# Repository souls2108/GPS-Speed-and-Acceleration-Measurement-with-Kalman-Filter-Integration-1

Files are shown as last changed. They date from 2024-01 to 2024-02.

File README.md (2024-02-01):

# GPS-Speed-and-Acceleration-Measurement-with-Kalman-Filter-Integration
 GPS-based system for accurately measuring speed and acceleration, applying Kalman filtering techniques for enhanced precision. The system further includes a user-friendly OLED display for real-time speed visualization.

### Description:

GPS Speedometer project repository: This open-source project aims to provide a comprehensive GPS-based system for accurately measuring speed and acceleration, applying Kalman filtering techniques for enhanced precision. The system further includes a 1.5 inch OLED display for real-time speed visualization and a web interface for remote monitoring.<b>This project was implemented to measure vehicle telemetry for Team Firebolt Racing in mBAJA 2024 (SAEINDIA).</b>

### Hardware used:
<ol>
 <li>ublox NEO-6M</li>
 <li><a href="https://robu.in/product/gps-glonass-gnss-antenna-for-raspberry-pi-hat-and-arduino-shield-with-3-meter-cable/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">GPS antenna (for better performance)</a></li>
 <li>BNO085 9DoF (accelerometer, gyroscope, magnetometer)</li>
 <li>NodeMCU v1.0</li>
 <li>1.5 inch OLED display by Waveshare [SSD1327]</li>
</ol>

## Features:
## 1. GPS-Based Speed and Acceleration Measurement
Utilizing GPS data, the system accurately calculates and measures real-time speed and acceleration. The integration of GPS technology ensures reliable and precise location-based speed readings.

## 2. Kalman Filter Implementation
To enhance the accuracy of speed and acceleration measurements, a Kalman filter is applied. The Kalman filter optimally combines GPS data with accelerometer readings, resulting in more reliable and smoother speed values, particularly in scenarios with signal noise or intermittent GPS connectivity.

## 3. OLED Display
The project includes an OLED display to provide a convenient and intuitive interface for users to monitor their speed in real time. The display showcases clear and easily readable speed information, making it suitable for various applications, such as automotive or fitness devices.

## 4. Webpage Display
For remote monitoring and data visualization, the system features a web interface. Users can access a webpage that displays real-time speed information, allowing for convenient monitoring without the need for physical interaction with the OLED display. The web interface supports multiple devices, providing a flexible and accessible solution.

## Getting Started:
1. Clone the repository to your local machine.
2. Install the required dependencies mentioned in the documentation.
3. Make the required changes in configuration to GPS module using U - Center software.
4. Connect the GPS module, BNO085 and OLED display to NodeMCU to set-up. 
5. Upload the provided code to your microcontroller.
6. Access the web interface to monitor real-time speed remotely.

### Port Map
<ul>
  <li>OLED SCREEN</li>
   <ol>
    <li>VCC -> 3V</li>
    <li>GND -> GND</li>
    <li>DIN -> D7</li>
    <li>CLK -> D5</li>
    <li>CS -> D8</li>
    <li>DC -> D0</li>
    <li>RST -> D3</li>
   </ol>

  <li>BNO085</li>
   <ol>
    <li>VIN -> 3V</li>
    <li>GND -> GND</li>
    <li>SCL -> D1</li>
    <li>SDA -> D2</li>
    <li>P0 -> GND</li>
    <li>P1 -> GND</li>
   </ol>

   <li>GPS</li>
   <ol>
    <li>VCC -> 3V</li>
    <li>GND -> GND</li>
    <li>RX -> D4</li>
    <li>TX -> D6</li>
   </ol>
</ul>

## Contribution Guidelines:
Welcome for contributions to enhance and expand the capabilities of this GPS speedometer system. Feel free to submit bug reports, feature requests, or pull requests to help improve the project.

Thank you for choosing our GPS Speedometer project. We hope it proves to be a valuable tool for your speed measurement and monitoring needs!

## References
<ul>
 <li>
  <a href = "https://youtu.be/TwhCX0c8Xe0?si=p0fIQ2RGdnS_CM2-">GPS Configuration Reference</a>
 </li>
 <li>
  <a href="https://github.com/olikraus/u8g2.git">Library for OLED display</a>
 </li>
 <li>
  <a href = "https://github.com/adafruit/Adafruit_BNO08x.git">Library for BNO085</a>
 </li>
 <li>
  <a href="https://youtu.be/6M6wSLD-8M8?si=LIJLbGDBOQZDQuQw">Kalman Filter Basics</a>
 </li>
 <li>
  <a href="https://github.com/morrissinger/ESP8266-Websocket.git">ESP8266 Web Sockets</a>
 </li>
</ul>

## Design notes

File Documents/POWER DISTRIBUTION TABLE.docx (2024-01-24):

# POWER DISTRIBUTION TABLE

UNIT NAME | SAMPLE RATE (Hz) | POWER (mW)
IMU – BNO085 | 400 | 45.45
GPS module – Ublox Neo 6M | 5 | 165
Oled display – SSD1327 | - | 13.2 - 198
Node MCU | | 231 - 495
| | 454.65 - 903.45

Typical hours of operation – 20 Hr

Operating Voltage – 3.3 V

Energy consumption – {454.65 - 903.45} x 20 = {9093 – 18069} mWh

= {9093 – 18069} ÷ 3.3 = {2755.45 – 5475.45} mAh

Operating power of Brake light = 1 W

Typical hours of operation = 10 Hr

Typical operating voltage = 7 V

Energy consumption = 1 x 10 = 10 Wh

= (10×1000)/7= 1428.57 mAh

NET ENERGY CONSUMPTION = {4184.02 – 6904.02} mAh

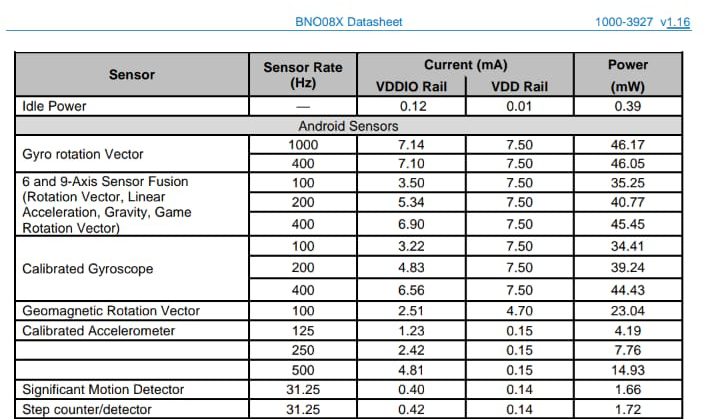
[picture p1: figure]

Other options :-

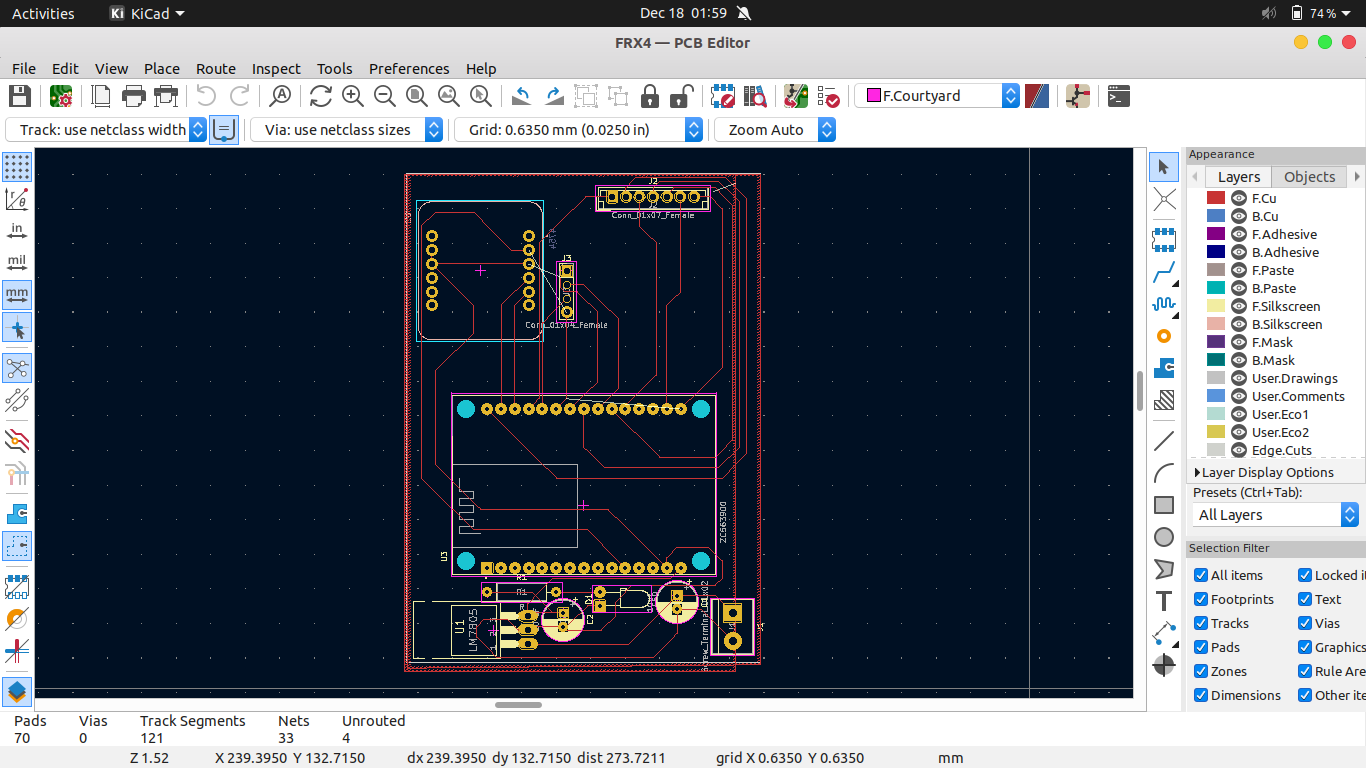
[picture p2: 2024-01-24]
Documents/PCB/Screenshot from 2023-12-18 01-59-36.png

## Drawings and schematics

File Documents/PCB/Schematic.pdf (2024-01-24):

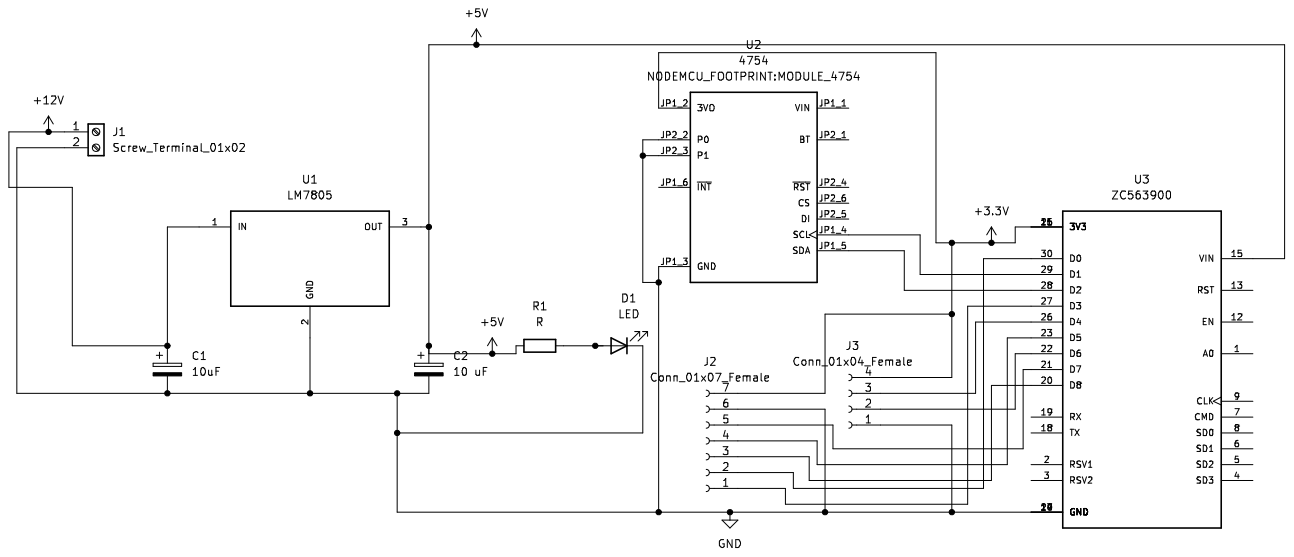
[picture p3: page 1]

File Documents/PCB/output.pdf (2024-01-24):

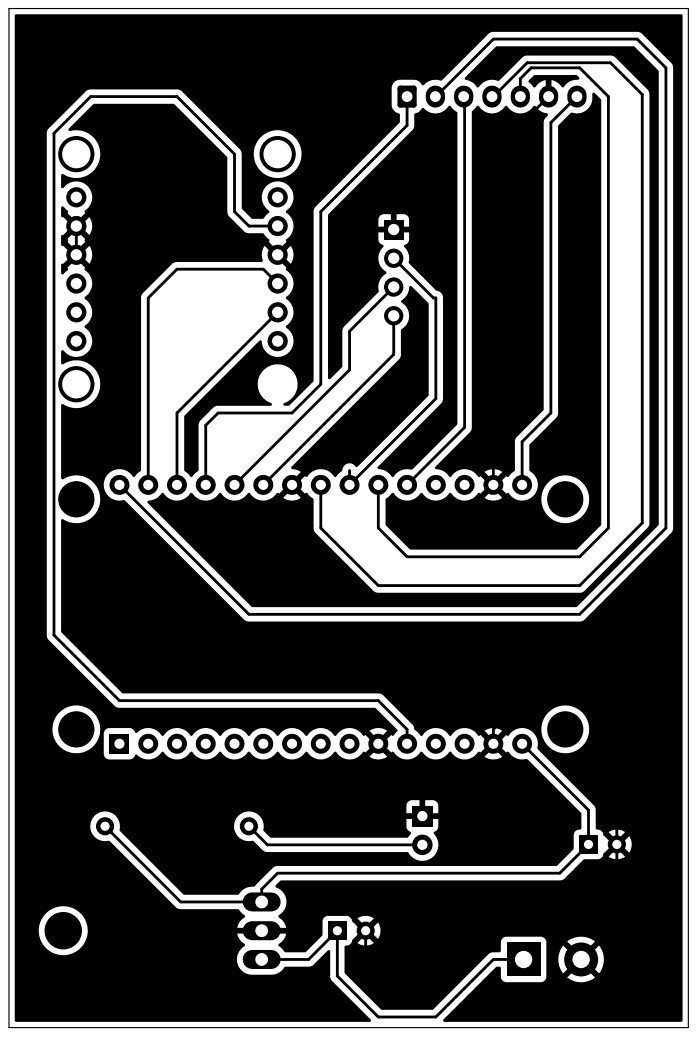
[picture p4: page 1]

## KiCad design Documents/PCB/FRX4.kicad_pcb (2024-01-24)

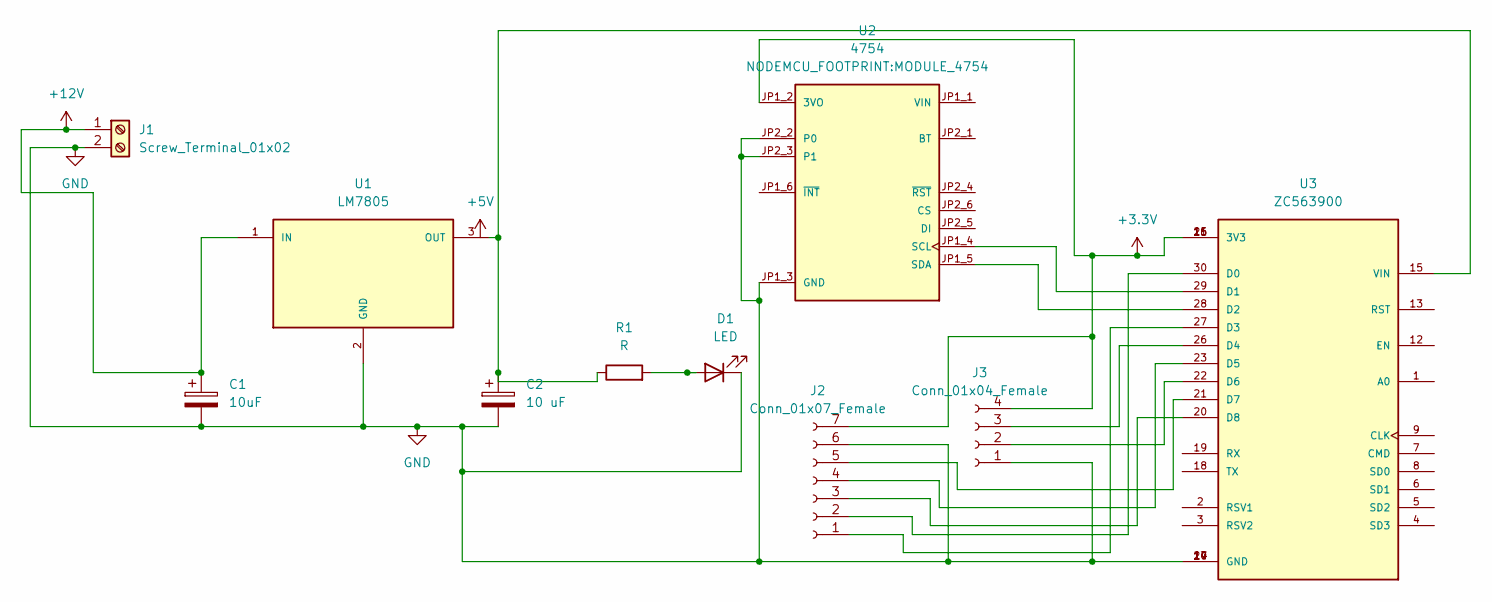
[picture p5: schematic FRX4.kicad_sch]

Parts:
C1: 10uF; CP_Radial_D10.0mm_P7.50mm
C2: 10 uF; CP_Radial_D10.0mm_P7.50mm
D1: LED; LED_D3.0mm_Horizontal_O3.81mm_Z10.0mm
J1: Screw_Terminal_01x02; TerminalBlock_bornier-2_P5.08mm
J2: Conn_01x07_Female; JST_EH_B7B-EH-A_1x07_P2.50mm_Vertical
J3: Conn_01x04_Female; PinHeader_1x04_P2.54mm_Vertical
R1: R; R_Axial_DIN0309_L9.0mm_D3.2mm_P12.70mm_Horizontal
U1: LM7805; TO220
U2: 4754; MODULE_4754; PARTREV 2021-03-16
U3: ZC563900; MODULE_ZC563900; PARTREV 1.0

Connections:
+3.3V: J2.7, J3.4, U2.JP1_2 (3VO), U3.11 (3V3), U3.16 (3V3), U3.25 (3V3)
+5V: C2.1, R1.1, U1.3 (OUT), U3.15 (VIN)
+12V: C1.1, J1.1, U1.1 (IN)
GND: C1.2, C2.2, D1.1 (K), J1.2, J2.6, J3.1, U1.2 (GND), U2.JP1_3 (GND), U2.JP2_2 (P0), U2.JP2_3 (P1), U3.10 (GND), U3.14 (GND), U3.17 (GND), U3.24 (GND)
unnamed: D1.2 (A), R1.2
unnamed: J2.1, U3.27 (D3)
unnamed: J2.2, U3.30 (D0)
unnamed: J2.3, U3.20 (D8)
unnamed: J2.4, U3.23 (D5)
unnamed: J2.5, U3.21 (D7)
unnamed: J3.2, U3.22 (D6)
unnamed: J3.3, U3.26 (D4)
unnamed: U2.JP1_4 (SCL), U3.29 (D1)
unnamed: U2.JP1_5 (SDA), U3.28 (D2)

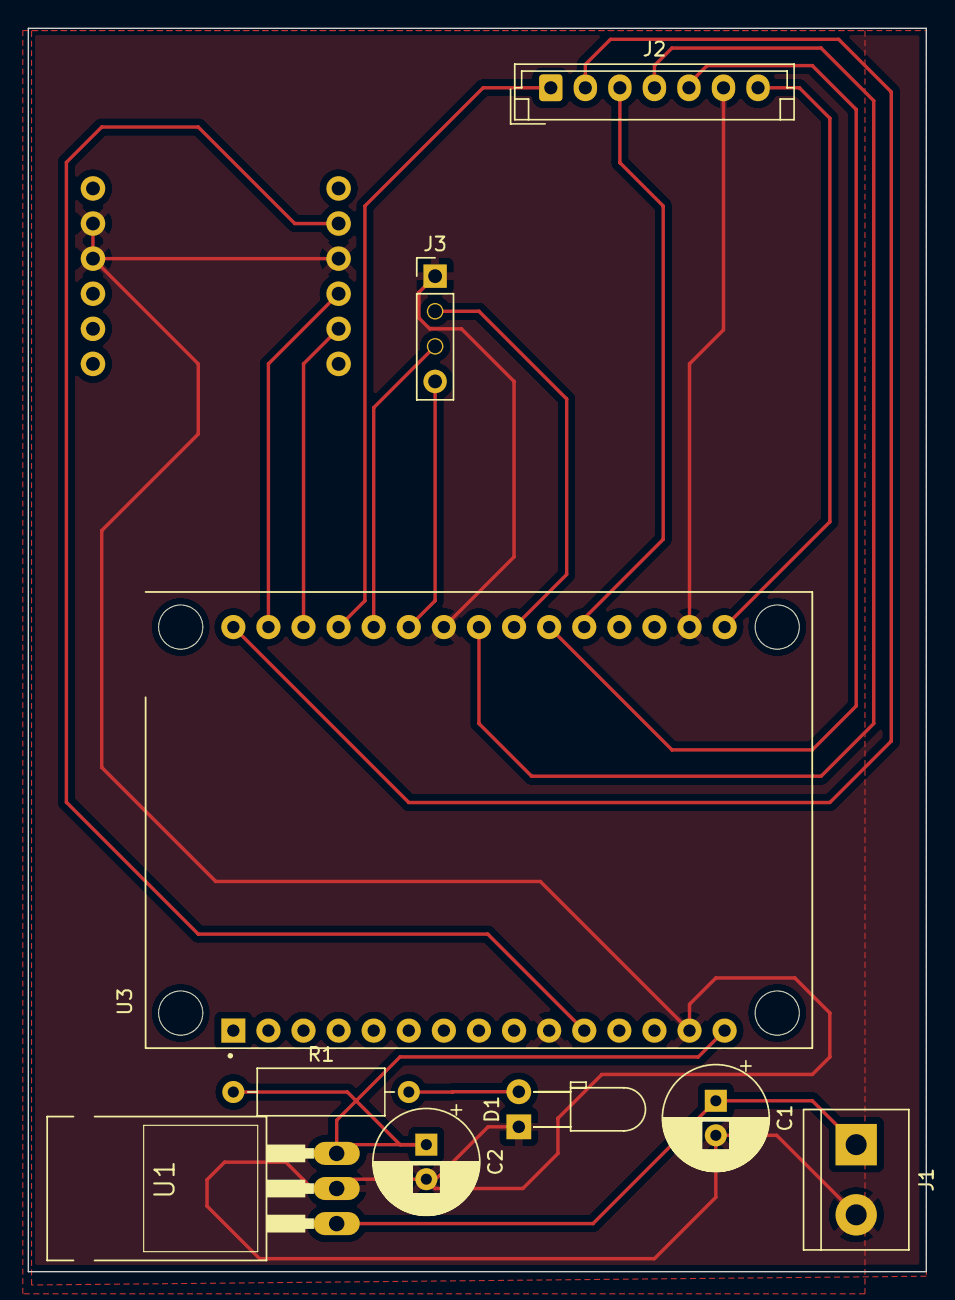
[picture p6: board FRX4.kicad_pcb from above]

Board: 2 copper layers, 65.0 x 90.0 mm, 10 parts (1 on the bottom side), 14 nets.

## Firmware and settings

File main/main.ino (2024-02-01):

#include <U8g2lib.h>
#include <Adafruit_BNO08x.h>
#include <math.h>
#include <quaternion_type.h>
// #include <Wire.h>
// #include  <SPI.h>
// #include <SoftwareSerial.h>
#include <ESP8266WiFi.h>
#include <ESP8266WebServer.h>
#include <WebSocketsServer.h>
//-------------------VARIABLES YOU MAY NEED TO CHANGE------------------------
#define D1 5
#define D2 4
#define D3 0
#define D4 2
#define D6 12

#define IMU_noise 1
const char *ssid = "NNN";
const char *password = "00000000";
#define IP_display_delay 700
//to make changes to oled display check layout init function
//---------------------------------------------------------------------------

//------INITIALISATION OF HARDWARE OBJECTS-----------------------------------
SoftwareSerial GPS(/*GPS TX = */ D6, /*GPS RX = */D4);  // TX, RX pins for GPS connection
Adafruit_BNO08x bno08x(-1);
sh2_SensorValue_t sensorValue;
ESP8266WebServer server(80);
WebSocketsServer webSocket = WebSocketsServer(81);
/*
CLK GPIO 14 D5
MOSI GPIO 13  D7
CS  15  D8
RST D3
DC  D0
*/
U8G2_SSD1327_WS_128X128_F_4W_HW_SPI u8g2(U8G2_R0, /* cs=*/ 15, /* dc=*/ 16, /* reset=*/ 0);
typedef u8g2_uint_t u8g_uint_t; 

//------ GPS related functions ----------------------------------------------- 
// DATA PACKET RECIEVED FROM UBLOX GPS MODULE
const unsigned char UBX_HEADER[] = { 0xB5, 0x62 };
struct NAV_VELNED {
  unsigned char cls;
  unsigned char id;
  unsigned short len;

  unsigned long int iTOW;
  long int velN;
  long int velE;
  long int velD;
  unsigned long int speed;
  unsigned long int gSpeed;
  long int heading;
  unsigned long int sAcc;
  unsigned long int cAcc;
};
NAV_VELNED velned;

void calcChecksum(unsigned char* CK) {
  memset(CK, 0, 2);
  for (int i = 0; i < (int)sizeof(NAV_VELNED); i++) {
    CK[0] += ((unsigned char*)(&velned))[i];
    CK[1] += CK[0];
  }
}

bool processGPS() {
  static int fpos = 0;
  static unsigned char checksum[2];
  const int payloadSize = sizeof(NAV_VELNED);

  while ( GPS.available() ) {
    byte c = GPS.read();
    if ( fpos < 2 ) {
      if ( c == UBX_HEADER[fpos] )
        fpos++;
      else
        fpos = 0;
    }
    else {      
      if ( (fpos-2) < payloadSize )
        ((unsigned char*)(&velned))[fpos-2] = c;

      fpos++;

      if ( fpos == (payloadSize+2) ) {
        calcChecksum(checksum);
      }
      else if ( fpos == (payloadSize+3) ) {
        if ( c != checksum[0] )
          fpos = 0;
      }
      else if ( fpos == (payloadSize+4) ) {
        fpos = 0;
        if ( c == checksum[1] ) {
          return true;
        }
      }
      else if ( fpos > (payloadSize+4) ) {
        fpos = 0;
      }
    }
  }
  return false;
}

//------------ IMU functions ------------------------------------------
struct NED {
  float N;
  float E;
  float D;
  unsigned long log_time;
};
unsigned long last_gps_log_time = 0;
float prev_process_error = 20;
NED accNED;
NED filtered_speedNED;
quat_t quat;
#define low_val_offset 0.07 //ignore small accelerations when stationary


void setReports(void) {
  displayMessage("Setting desired","reports");
  if (!bno08x.enableReport(SH2_LINEAR_ACCELERATION)) {
    displayMessage("Could not enable","linear acceleration");
  }
  if (!bno08x.enableReport(SH2_GEOMAGNETIC_ROTATION_VECTOR) ) {
    displayMessage("Could not enable geomagnetic","rotation vector");
  }
  // if (!bno08x.enableReport(SH2_ARVR_STABILIZED_RV, 5000)) {
  //   Serial.println("Could not enable SH2_ARVR_STABILIZED_RV");
  // }
}

int processIMU() {  
  if (bno08x.wasReset()) {
    Serial.print("sensor was reset ");
    setReports();
  }
  if (!bno08x.getSensorEvent(&sensorValue)) {
    return 0;
  }
  switch (sensorValue.sensorId) {
    case SH2_LINEAR_ACCELERATION: {
      quat_t qa = { 0, sensorValue.un.linearAcceleration.x,
      sensorValue.un.linearAcceleration.y,
      sensorValue.un.linearAcceleration.z};
      quat = quat.norm();
      quat_t res = quat * qa * quat.conj();
      accNED.N = res.v.y;
      accNED.E = res.v.x;
      accNED.D = -res.v.z;
      if(accNED.N < low_val_offset && accNED.N > -low_val_offset) {
        accNED.N = 0;
      }
      if(accNED.E < low_val_offset && accNED.E > -low_val_offset) {
        accNED.E = 0;
      }
      if(accNED.D < low_val_offset && accNED.D > -low_val_offset) {
        accNED.D = 0;
      }
      accNED.log_time = micros();
      return 1;
    }

    case SH2_GEOMAGNETIC_ROTATION_VECTOR: {
      quat = { sensorValue.un.geoMagRotationVector.real, 
      sensorValue.un.geoMagRotationVector.i,
      sensorValue.un.geoMagRotationVector.j,
      sensorValue.un.geoMagRotationVector.k};
      return 2;
    }
  } 
  return 0;
}
struct euler_t {
  float yaw;
  float pitch;
  float roll;
};
euler_t ypr;
void quaternionToEuler(float qr, float qi, float qj, float qk) {

    float sqr = sq(qr);
    float sqi = sq(qi);
    float sqj = sq(qj);
    float sqk = sq(qk);

    ypr.yaw = atan2(2.0 * (qi * qj + qk * qr), (sqi - sqj - sqk + sqr));
    ypr.pitch = asin(-2.0 * (qi * qk - qj * qr) / (sqi + sqj + sqk + sqr));
    ypr.roll = atan2(2.0 * (qj * qk + qi * qr), (-sqi - sqj + sqk + sqr));

    // conversion to degrees 
    ypr.yaw *= RAD_TO_DEG;
    ypr.pitch *= RAD_TO_DEG;
    ypr.roll *= RAD_TO_DEG;
}

//-------CORE PROCESS COLLECTING AVAILABLE DATA (KALMAN FILTER APPLIED HERE)--------------------------------------------

void process() {
  if (processGPS()) {
    unsigned long now = micros();
    float time_gps = (now - last_gps_log_time) / 1000000.0;
    last_gps_log_time = now;
    /*BNO085 datasheet mentions error in linear acc - 0.35 m/s², but 1 m/s² noise worked for me*/
    prev_process_error += sq(IMU_noise * time_gps); 
    float kalmanGain = prev_process_error / ( prev_process_error + sq(velned.sAcc / 100.0));
    filtered_speedNED.N = filtered_speedNED.N + kalmanGain * ((velned.velN / 100.0) - filtered_speedNED.N);
    filtered_speedNED.E = filtered_speedNED.E + kalmanGain * ((velned.velE / 100.0) - filtered_speedNED.E);
    filtered_speedNED.D = filtered_speedNED.D + kalmanGain * ((velned.velD / 100.0) - filtered_speedNED.D);
    filtered_speedNED.log_time = now;
    prev_process_error = (1 - kalmanGain) * prev_process_error; //Update error covariance


    Serial.print("spd GPS:0,");
    Serial.print("N:");
    Serial.print(filtered_speedNED.N);
    Serial.print(",E:");
    Serial.print(filtered_speedNED.E);
    Serial.print(",D:");
    Serial.print(filtered_speedNED.D);
    Serial.print(",kg:");
    Serial.print(kalmanGain);
    Serial.print(",log_time:");
    Serial.print(filtered_speedNED.log_time);
    Serial.println();


    // Serial.print("GPS:0,");  
    Serial.print("velnedN:");
    Serial.print(velned.velN / 100.0);
    Serial.print(",velnedE:");
    Serial.print(velned.velE / 100.0);
    Serial.print(",velnedD:");
    Serial.print(velned.velD / 100.0);
    Serial.print(",spdAcc:");
    Serial.print(velned.sAcc / 100.0);
    Serial.println();

    return;
  }
  switch (processIMU()) {
    case 1: /* Integrate if new acceleration reading is recieved*/ {
      float time_acc = (accNED.log_time - filtered_speedNED.log_time)/1000000.0; //conversion micro secs to secs without loss float precision
      filtered_speedNED.N += accNED.N * time_acc;
      filtered_speedNED.E += accNED.E * time_acc;
      filtered_speedNED.D += accNED.D * time_acc;
      filtered_speedNED.log_time = accNED.log_time;
      
      Serial.print("spd acc:0,");
      Serial.print("N:");
      Serial.print(filtered_speedNED.N);
      Serial.print(",E:");
      Serial.print(filtered_speedNED.E);
      Serial.print(",D:");
      Serial.print(filtered_speedNED.D);
      // Serial.print(",log_time:");
      // Serial.print(filtered_speedNED.log_time);
      Serial.println();

      
      Serial.print("Type:4,");
      Serial.print("N:");
      Serial.print(accNED.N);
      Serial.print(",E:");
      Serial.print(accNED.E);
      Serial.print(",D:");
      Serial.print(accNED.D);
      // Serial.print(",log_time:");
      // Serial.print(accNED.log_time);
      Serial.println();
      break;
    }
    case 2:
      /*Update ypr subract from ypr offset, yaw value invalid*/
      quaternionToEuler(quat.w, quat.v.x, quat.v.y, quat.v.z);

      // Serial.print("Type:2,");
      // Serial.print("yaw:");
      // Serial.print(ypr.yaw);
      // Serial.print(",pitch:");
      // Serial.print(ypr.pitch);
      // Serial.print(",roll:");
      // Serial.print(ypr.roll);
      // Serial.println();
      break;

    case 0:
      //Serial.println(0);
      break;
  }
}

//initialisation of variables for kalman filter
void varDefaultInit() {
      filtered_speedNED.N = 0; accNED.N = 0;
      filtered_speedNED.E = 0; accNED.E = 0;
      filtered_speedNED.D = 0; accNED.D = 0;
      filtered_speedNED.log_time = 0; accNED.log_time = 0;
      velned.sAcc = 2000;
}

/*      ------------    SCREEN HANDLER    ------------      */
// void displayScreen(){
//   u8g2.clearBuffer();
//   u8g2.setFontMode(0);
//   u8g2.setFont(u8g2_font_helvR14_tf);

//   // u8g2.setCursor(10, 10);
//   // u8g2.print("Screen Test");

//   u8g2.setCursor(10 , 30);
//   u8g2.print(sqrt(sq(filtered_speedNED.N) + sq(filtered_speedNED.E) + sq(filtered_speedNED.D)));

//   u8g2.setCursor(u8g2.getDisplayWidth()/2 , 30);
//   u8g2.print(sqrt(sq(accNED.N) + sq(accNED.E) + sq(accNED.D)));

//   u8g2.setFont(u8g2_font_5x7_mf);
//   u8g2.setCursor(0, u8g2.getDisplayHeight() - 10);
//   u8g2.print(ypr.yaw);
//   u8g2.print(" ");
//   u8g2.print(ypr.pitch);
//   u8g2.print(" ");
//   u8g2.print(ypr.roll);

//   u8g2.sendBuffer();
//   delay(1);
// }

struct Layout {
  const uint8_t* font1;
  const uint8_t* font2;
  const uint8_t* font3;
  const uint8_t* font4;

  u8g_uint_t spd_x;
  u8g_uint_t spd_y;

  u8g_uint_t dial_x;
  u8g_uint_t dial_y;
  u8g_uint_t rad_in;
  u8g_uint_t rad_out;
  unsigned int aSpace;

  u8g_uint_t acc_x;
  u8g_uint_t acc_y;
  u8g_uint_t bar_width;

  u8g_uint_t kmph_txt_x;
  u8g_uint_t kmph_txt_y;
};
Layout layout;

void layoutinit() {
  // fonts
  layout.font1 =  u8g2_font_logisoso54_tf;
  layout.font2 =  u8g2_font_helvR24_tf;
  layout.font3 =  u8g2_font_courR12_tf;
  layout.font4 =  u8g2_font_courR12_tf;

  //center dial
  u8g_uint_t width = 4;
  layout.dial_x = u8g2.getDisplayWidth() / 2;
  layout.rad_out = u8g2.getDisplayWidth() / 2;
  layout.rad_in = layout.rad_out - width;
  layout.dial_y = u8g2.getDisplayHeight() - (cos(radians(45)) * layout.rad_out);
  layout.aSpace = 30;
  
  //top bar
  layout.bar_width = 8;

  //speed txt
  layout.spd_x = u8g2.getDisplayWidth() / 2;
  layout.spd_y = u8g2.getDisplayHeight() / 2;

  //acc txt
  layout.acc_x = u8g2.getDisplayWidth() - 30;
  layout.acc_y = u8g2.getDisplayHeight() - 30;

  //kmph txt
  layout.kmph_txt_x = u8g2.getDisplayWidth() / 2 - (layout.rad_in * cos(radians(45))) + /*padding */ 5;
  layout.kmph_txt_y = u8g2.getDisplayHeight() - width / 2 - /*padding*/ 5;

}

void displayScreen() {
  u8g2.clearBuffer();

  //Speed txt
  unsigned int speedkmph = int(sqrt(sq(filtered_speedNED.N) + sq(filtered_speedNED.E) + sq(filtered_speedNED.D)) * 3.6);
  u8g2.setFont(layout.font1);
  String buf = String(speedkmph);
  u8g2.setCursor(layout.spd_x - (u8g2.getStrWidth(buf.c_str())) / 2, layout.spd_y);
  u8g2.setFontPosCenter();
  u8g2.print(speedkmph);
  u8g2.setFontMode(0);

  //Drawing dots of arc
  for(int i = 225; i >= 0; i = i - layout.aSpace) {
    u8g2.drawBox(layout.dial_x + layout.rad_out * cos(radians(i)), layout.dial_y - layout.rad_out * sin(radians(i)), 2, 2);
  }
  //Drawing dial arc
  u8g2_draw_arc(layout.dial_x, layout.dial_y, layout.rad_in, layout.rad_out, 225 - ((speedkmph * 225) / /*max spd*/ 100 ), 225);

  //Acc txt
  unsigned int acc = int(sqrt(sq(accNED.N) + sq(accNED.E) /*+ sq(accNED.D)*/)); //Maybe Down causes noise ??
  u8g2.setFont(layout.font2);
  u8g2.setCursor(layout.acc_x, layout.acc_y);
  u8g2.setFontPosCenter();
  u8g2.print(acc);  
  //Draw acc bar
  u8g2.drawBox(0, 0, (u8g2.getDisplayWidth() * acc) / /*max_acc*/ 20, /*bar width - */ layout.bar_width);

  //Print kmph
  u8g2.setFont(layout.font3);
  u8g2.setCursor(layout.kmph_txt_x, layout.kmph_txt_y);
  u8g2.setFontPosCenter();
  u8g2.print("Kmph");



  u8g2.sendBuffer();
}
void displayMessage(String msg){
  displayMessage(msg, "");
}
void displayMessage(String msg, String msg_small) {
  Serial.println(msg);
  u8g2.clearBuffer();

  u8g2.setFont(layout.font3);
  u8g2.setFontPosCenter();
  u8g2.setCursor(2, 15);
  u8g2.print("[Info]");
  u8g2.setCursor(1, 50);
  u8g2.print(msg.c_str());
  u8g2.setCursor(1, 70);
  u8g2.print(msg_small.c_str());

  u8g2.sendBuffer();
  // delay(1000);
}

//-------------WEBPAGE STUFF------------------------------
void displayWebpage(){
  unsigned int speedkmph = int(sqrt(sq(filtered_speedNED.N) + sq(filtered_speedNED.E) + sq(filtered_speedNED.D)) * 3.6);
  unsigned int acc = int(sqrt(sq(accNED.N) + sq(accNED.E) /*+ sq(accNED.D)*/)); //Maybe Down causes noise ??
  server.handleClient();
  webSocket.loop();

  // String payload = "Speed : " + String(speedkmph) + " kmph" + "  " + 
  //               "Acc : " + String(acc) + " m/s²";
  int sensorValue = speedkmph;
  String payload = String(sensorValue);
  webSocket.broadcastTXT(payload);

}

void handleRoot() {
  String html = "<html><body>";
  html += "<h1>Sensor Data</h1>";
  html += "<p id='speedkmph'>Loading...</p>";
  html += "<script>var socket1 = new WebSocket('ws://' + window.location.hostname + ':81/');";
  html += "socket1.onmessage = function(event) {document.getElementById('speedkmph').innerHTML = 'Speed(kmph): ' + event.data;};";
  html += "</script>";

  html += "<p id='acc'>Loading...</p>";
  html += "<script>var socket = new WebSocket('ws://' + window.location.hostname + ':81/');";
  html += "socket.onmessage = function(event) {document.getElementById('acc').innerHTML = 'Acceleration(m/s²): ' + event.data;};";
  html += "</script>";
  html += "</body></html>";

  server.send(200, "text/html", html);
}
//---------------------------------------------------------

// void debug_gps() {  
//   Serial.print(velned.cls);
//   Serial.print(","); Serial.print(velned.id);
//   Serial.print(","); Serial.print(velned.len);
//   Serial.print(",");Serial.print(velned.iTOW);
//   Serial.print(","); Serial.print(velned.velN);
//   Serial.print(","); Serial.print(velned.velE);
//   Serial.print(","); Serial.print(velned.velD);
//   Serial.print(","); Serial.print(velned.speed);
//   Serial.print(","); Serial.print(velned.gSpeed);
//   Serial.print(","); Serial.print(velned.heading);
//   Serial.print(","); Serial.print(velned.sAcc);
//   Serial.print(","); Serial.print(velned.cAcc);
//   Serial.println();

//   u8g2.clearBuffer();
//   u8g2.setFontMode(0);
//   u8g2.setFont(u8g2_font_helvR14_tf);
//   u8g2.setCursor(0,20);

//   u8g2.print(velned.velN); u8g2.print(","); u8g2.print(velned.velE); u8g2.print(","); u8g2.print(velned.velD);
//   u8g2.setCursor(0, 40);
//   u8g2.print(velned.speed); u8g2.print(","); u8g2.print(velned.sAcc);
//   u8g2.sendBuffer();
// }


//---------NodeMCU setup and hardware checkup--------------------------
void setup() {
  u8g2.begin();
  // u8g2.enableUTF8Print();
  layoutinit();

  Serial.begin(9600);
  Serial.flush();

  WiFi.mode(WIFI_AP);
  WiFi.softAP(ssid, password);

  server.on("/", HTTP_GET, handleRoot);
  webSocket.begin();
  server.begin();
  displayMessage("IP address:", WiFi.softAPIP().toString());
  delay(IP_display_delay);
  displayMessage("Server active");
  delay(IP_display_delay);

  GPS.begin(9600);
  GPS.flush();

  if (!bno08x.begin_I2C()) {
    displayMessage("Failed to find","BNO08x chip");
    while (1) {
      delay(10);
    }
  }
  displayMessage("BNO08x Found!");
  setReports(); //SETTING imu BNO085 mode

  displayMessage("Checking sensor status.");
  varDefaultInit();
  checkSensorStatus();
}

void checkSensorStatus() {
  do {
    bno08x.getSensorEvent(&sensorValue);
    displayMessage("BNO085 : " + String(sensorValue.status));
    delay(1);
  } while(sensorValue.status != 3);
  do {
      processGPS();
      displayMessage("GPS : " + String(velned.sAcc / 100));
      delay(1000);
  } while(2000 == velned.sAcc);
}

void loop() {
  // Serial.println(".");
  process();
  // if(processGPS())
  //   debug_gps();
  displayScreen();
  displayWebpage();
}


static const float pi_2 = 1.57079632679489661923;
static const float pi_4 = 0.78539816339744830962;
static void u8g2_draw_arc(u8g2_uint_t x0, u8g2_uint_t y0, u8g2_uint_t rad_in, u8g2_uint_t rad_out, u8g2_uint_t angle_start, u8g2_uint_t angle_end)
{
  // Declare variables
  u8g2_long_t x, y, d, r, as, ae, cnt, num_pts;

  // Manage angle inputs
  uint8_t inverted = (angle_start > angle_end);
  as = inverted ? angle_end : angle_start;
  ae = inverted ? angle_start : angle_end;

  // Trace each arc radius with the Andres circle algorithm
  for(r = rad_in; r <= rad_out; r++)
  {
    x = 0;
    y = r;
    d = r - 1;
    //num_pts = atan2f_func ? 100 : (r * 8 / 10); // if no atan2f() function is provided, we make a low cost approximation of the number of pixels drawn for a 1/8th circle of radius r
    num_pts =100;
    // Process each pixel of a 1/8th circle of radius r
    while (y >= x)
    {
      // If atan2f() function is provided, get the percentage of 1/8th circle drawn, otherwise count the drawn pixels
      //cnt = atan2f_func ? ((pi_2 - atan2f_func(y, x)) * 100 / pi_4) : (cnt + 1);
      cnt = ((pi_2 - atan2f(y, x)) * 100 / pi_4);
      // Fill the pixels of the 8 sections of the circle, but only on the arc defined by the angles (start and end)
      if((cnt > num_pts * as / 45 && cnt <= num_pts * ae / 45) ^ inverted) u8g2.drawPixel(x0 + y, y0 - x);
      if((cnt > num_pts * (90 - ae) / 45 && cnt <= num_pts * (90 - as) / 45) ^ inverted) u8g2.drawPixel(x0 + x, y0 - y);
      if((cnt > num_pts * (as - 90) / 45 && cnt <= num_pts * (ae - 90) / 45) ^ inverted) u8g2.drawPixel(x0 - x, y0 - y);
      if((cnt > num_pts * (180 - ae) / 45 && cnt <= num_pts * (180 - as) / 45) ^ inverted) u8g2.drawPixel(x0 - y, y0 - x);
      if((cnt > num_pts * (as - 180) / 45 && cnt <= num_pts * (ae - 180) / 45) ^ inverted) u8g2.drawPixel(x0 - y, y0 + x);
      if((cnt > num_pts * (270 - ae) / 45 && cnt <= num_pts * (270 - as) / 45) ^ inverted) u8g2.drawPixel(x0 - x, y0 + y);
      if((cnt > num_pts * (as - 270) / 45 && cnt <= num_pts * (ae - 270) / 45) ^ inverted) u8g2.drawPixel(x0 + x, y0 + y);
      if((cnt > num_pts * (360 - ae) / 45 && cnt <= num_pts * (360 - as) / 45) ^ inverted) u8g2.drawPixel(x0 + y, y0 + x);

      // Run Andres circle algorithm to get to the next pixel
      if (d >= 2 * x)
      {
        d = d - 2 * x - 1;
        x = x + 1;
      } else if (d < 2 * (r - y))
      {
        d = d + 2 * y - 1;
        y = y - 1;
      } else
      {
        d = d + 2 * (y - x - 1);
        y = y - 1;
        x = x + 1;
      }
    }
  }
}

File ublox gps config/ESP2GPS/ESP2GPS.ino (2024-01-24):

#include <SoftwareSerial.h>
#define D0 16
#define D1 5
#define D2 4
#define D4 2
#define D6 12
SoftwareSerial gpsSerial(/*GPS TX = */ D6, /*GPS RX = */D4);  // TX, RX pins for GPS connection

void setup() {
  Serial.begin(9600);
  gpsSerial.begin(9600);
  Serial.flush();
  gpsSerial.flush();
}
void loop() {
  if (gpsSerial.available()) {
    Serial.write(gpsSerial.read());
  }
  if (Serial.available()) {
    gpsSerial.write(Serial.read());
  }
}
